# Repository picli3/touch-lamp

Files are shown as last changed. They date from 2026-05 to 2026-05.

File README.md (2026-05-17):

# Touch Lamp — Lámpara Vintage con Sensor Táctil

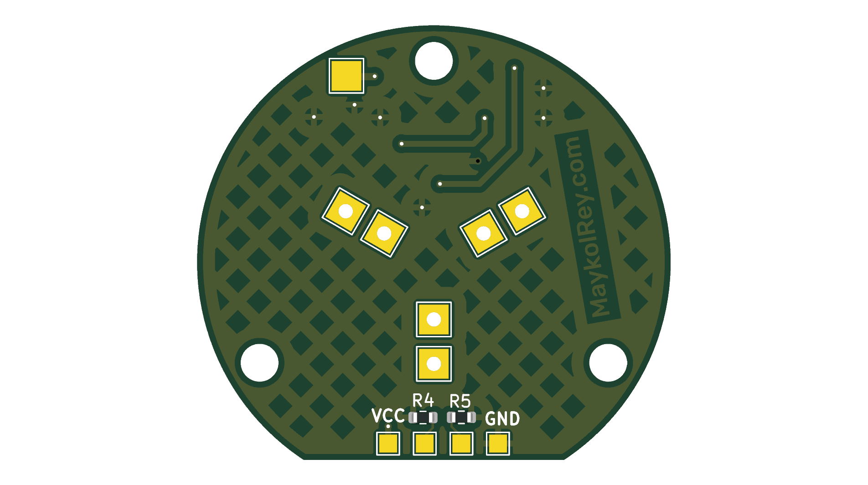
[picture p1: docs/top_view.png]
PCB Top View


PCB con 3 LEDs que simulan ser filamento incandescente, diseñada para integrarse en una **lámpara vintage**. El control táctil está basado en el circuito integrado **SGL8022W**, que permite encendido/apagado y regulación de intensidad luminosa (dimmer) con solo tocar el electrodo sensor.

## Características

- **Control táctil** basado en SGL8022W (SOP-8)
- **3 LEDs** dispuestos para simular un filamento incandescente vintage
- **Regulación de intensidad** — toques repetidos cambian el brillo (ciclo: apagado → bajo → medio → alto → apagado)
- **Alimentación:** 5 VCC
- **Formato compacto** ideal para montaje dentro de lámparas decorativas
- Diseñado en **KiCad 10.0**

## Componentes Principales

| Ref | Componente | Descripción | Footprint |
|-----|---|---|---|
| U1 | **SGL8022W** | IC touch sensor para regulación de brillo LED | SOP-8 |
| Q1 | NPN transistor | Driver de salida para LEDs | SOT-23-3 |
| D1-D3 | LED 0603 | LEDs simulando filamento incandescente | 0603 LED |
| C1 | 100 nF | Capacitor de desacople | 0603 |
| C2 | 10 µF | Capacitor de filtro de alimentación | 0805 |
| C3 | 10 nF | Capacitor de oscilación del SGL8022W | 0603 |
| R1 | 4.7 kΩ | Resistencia de polarización | 0603 |
| R2 | 1 kΩ | Resistencia de base del transistor | 0603 |
| R3 | 5.1 Ω | Resistencia limitadora de corriente de LEDs | 0603 |
| R4, R5 | 5.1 kΩ | Resistencias de configuración de modo | 0603 |

## Cómo Funciona

1. **Sensor táctil:** El SGL8022W detecta la capacitancia del cuerpo humano a través de un electrodo conectado al pin TI (Touch Input, pin 5).
2. **Procesamiento:** El chip interpreta los toques y controla la salida PWM en el pin SO (pin 7).
3. **Driver de salida:** La señal PWM pasa por un transistor NPN (Q1) que maneja los 3 LEDs en paralelo.
4. **Modos de operación:** Configurables mediante los pines OPT1/OPT2 y los jumpers JP1/JP2 en la PCB.

### Ciclo de operación por defecto

| Toque | Estado |
|---|---|
| 1er toque | Encendido — brillo bajo |
| 2do toque | Brillo medio |
| 3er toque | Brillo alto |
| 4to toque | Apagado |

## Archivos del Proyecto

| Archivo | Descripción |
|---|---|
| `lampara_bintge.kicad_sch` | Esquemático en KiCad |
| `lampara_bintge.kicad_pcb` | Diseño de PCB en KiCad |
| `lampara_bintge.kicad_pro` | Proyecto KiCad |
| `lampara_bintge.kicad_prl` | Archivo de diseño de placa |

## BOM (Bill of Materials)

El archivo `BOM.csv` incluido en los releases contiene la lista completa de materiales con referencias, valores, footprints y descripciones.

## Licencia

Este proyecto se comparte con fines educativos y de hobby. Si lo usas o modificas, agradeceremos la atribución.

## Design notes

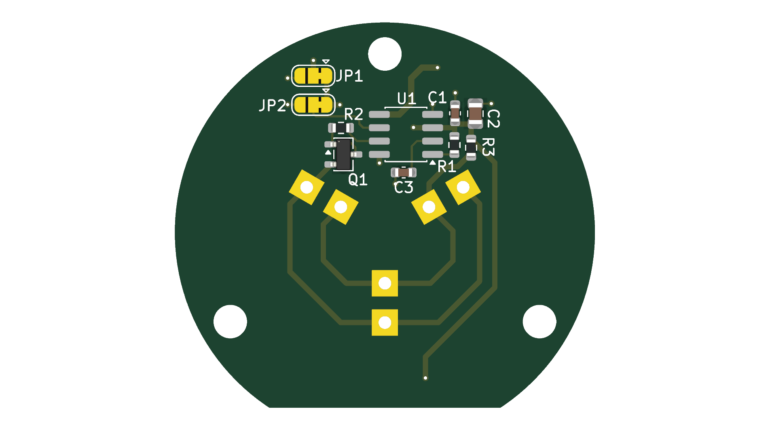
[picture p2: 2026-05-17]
docs/botton_view.png

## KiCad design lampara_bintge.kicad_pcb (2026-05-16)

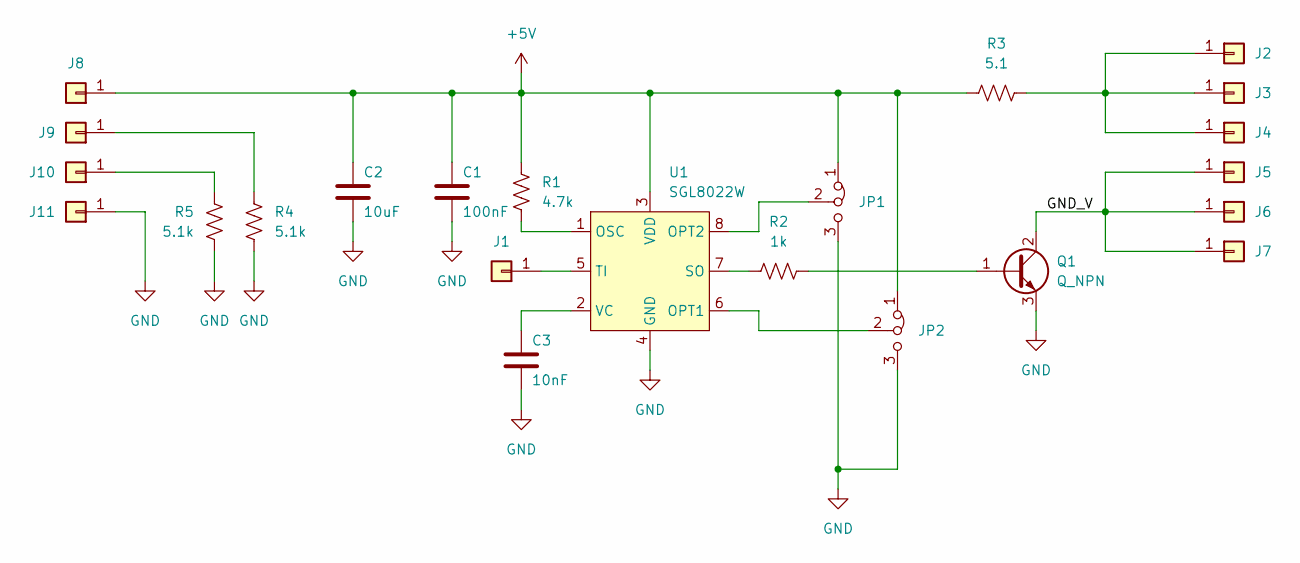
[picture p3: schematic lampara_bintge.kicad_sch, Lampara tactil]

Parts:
C1: 100nF; C_0603_1608Metric
C2: 10uF; C_0805_2012Metric
C3: 10nF; C_0603_1608Metric
J1: Conn_01x01; TestPoint_Pad_2.5x2.5mm
J2, J3, J4, J5, J6, J7: Conn_01x01; TestPoint_THTPad_2.5x2.5mm_Drill1.2mm
J8, J9, J10, J11: Conn_01x01; TestPoint_Pad_1.5x1.5mm
JP1, JP2: Jumper_3_Bridged12; SolderJumper-3_P1.3mm_Bridged12_RoundedPad1.0x1.5mm
Q1: Q_NPN; SOT-23-3
R1: 4.7k; R_0603_1608Metric
R2: 1k; R_0603_1608Metric
R3: 5.1; R_0603_1608Metric
R4, R5: 5.1k; R_0603_1608Metric
U1: SGL8022W; SOP-8_3.76x4.96mm_P1.27mm

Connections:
+5V: C1.1, C2.1, J8.1 (Pin_1_1), JP1.1 (A), JP2.1 (A), R1.2, R3.2, U1.3 (VDD)
/GND_V: J5.1 (Pin_1_1), J6.1 (Pin_1_1), J7.1 (Pin_1_1), Q1.2 (C)
GND: C1.2, C2.2, C3.2, J11.1 (Pin_1_1), JP1.3 (B), JP2.3 (B), Q1.3 (E), R4.1, R5.1, U1.4 (GND)
unnamed: J1.1 (Pin_1_1), U1.5 (TI)
unnamed: J2.1 (Pin_1_1), J3.1 (Pin_1_1), J4.1 (Pin_1_1), R3.1
unnamed: J9.1 (Pin_1_1), R4.2
unnamed: J10.1 (Pin_1_1), R5.2
unnamed: JP1.2 (C), U1.8 (OPT2)
unnamed: JP2.2 (C), U1.6 (OPT1)
unnamed: Q1.1 (B), R2.1
unnamed: R1.1, U1.1 (OSC)
unnamed: R2.2, U1.7 (SO)
unnamed: C3.1, U1.2 (VC)

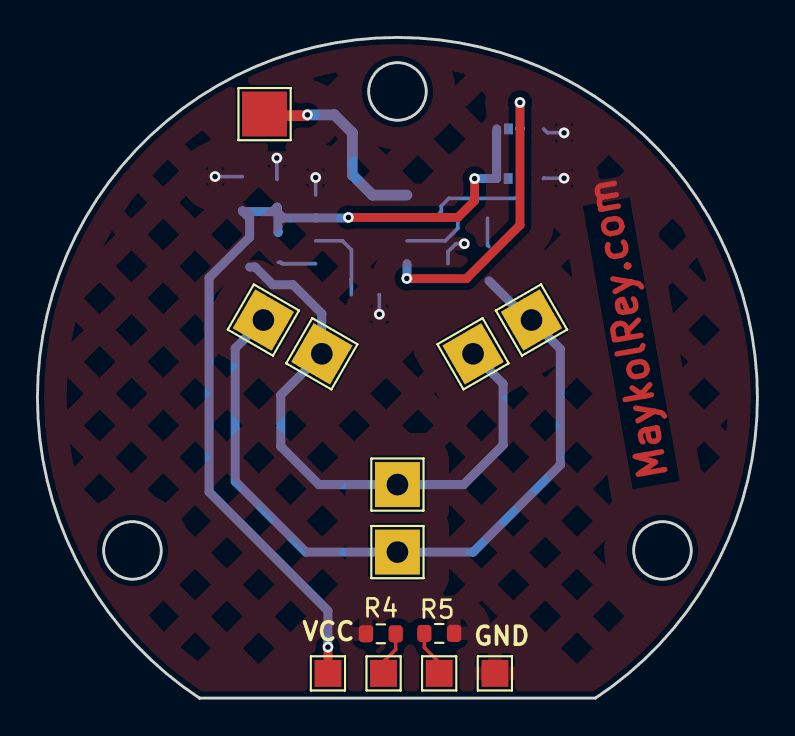
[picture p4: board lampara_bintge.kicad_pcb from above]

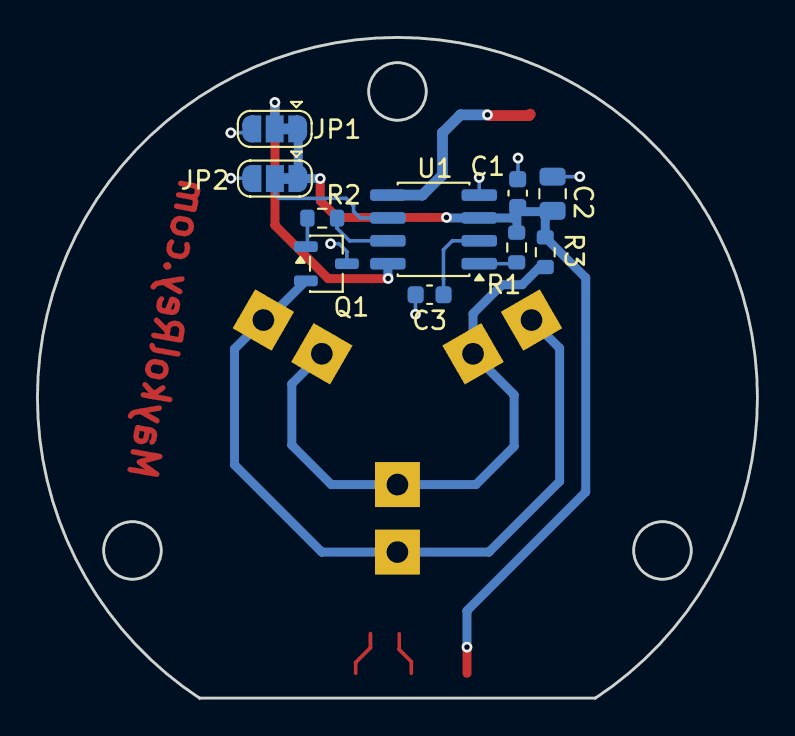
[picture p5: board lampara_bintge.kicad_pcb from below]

Board: 2 copper layers, 40.0 x 36.7 mm, 23 parts (10 on the bottom side), 13 nets.

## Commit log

2026-05-16 agregando sensor tactil
    [lampara_bintge.kicad_pcb, lampara_bintge.kicad_sch]
2026-05-17 docs: add README and board images for v1.0.0
    - README.md with full project description, BOM, and usage
    - Top and bottom PCB views in docs/
